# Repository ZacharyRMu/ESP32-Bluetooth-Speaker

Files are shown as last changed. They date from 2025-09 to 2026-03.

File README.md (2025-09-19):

# ESP32 Bluetooth Speaker with Controls

A DIY Bluetooth speaker project using an ESP32 microcontroller, a MAX98357A I²S DAC amplifier, and control buttons. Stream audio via Bluetooth A2DP, and control playback, track navigation, and volume directly from buttons.

---

## Table of Contents

- [Features](#features)  
- [Hardware Requirements](#hardware-requirements)  
- [Circuit / Wiring](#circuit--wiring)  
- [Software & Libraries](#software--libraries)  
- [Usage](#usage)  
- [Troubleshooting](#troubleshooting)  
- [Optional Enhancements](#optional-enhancements)  
- [Project Structure](#project-structure)  
- [License](#license)

---

## Features

- Bluetooth A2DP audio streaming from any compatible device (phone, computer, etc.)  
- Physical controls: play/pause, next/previous track, volume up/down  
- Uses I²S interface with MAX98357A amplifier for better audio quality  
- Configurable and extensible (add LEDs, battery, enclosures, etc.)

---

## Hardware Requirements

| Component | Description / Notes |
|---|---|
| ESP32 board | Any variant that supports Bluetooth + I²S; power via USB or external supply |
| MAX98357A I²S amplifier module | To convert digital audio to analog and drive the speaker |
| Speaker | 4 Ω or 8 Ω, approx. 3 W recommended |
| Push-buttons (×5) | For Play/Pause, Next Track, Previous Track, Volume Up, Volume Down |
| Jumper wires | For connections between ESP32, amplifier, buttons |
| Capacitor (10 µF, optional) | Between VIN and GND of amplifier to smooth power & reduce noise |
| Micro-USB cable | To program and power the ESP32 |
| Enclosure (optional) | To house the electronics nicely and safely |

---

## Circuit / Wiring

**Connections:**

- **Power**  
  - VIN on ESP32 → VIN on MAX98357A  
  - GND → GND (common ground)

- **I²S Audio Signals**  
  - I²S_BCLK (bit clock) → GPIO 27  
  - I²S_LRC (word select / left-right clock) → GPIO 14  
  - I²S_DIN (audio data) → GPIO 26  

- **Buttons** (one side of each button to GND; the other to the ESP32 GPIO pins)  
  - Play/Pause → GPIO 5  
  - Previous Track → GPIO 18  
  - Next Track → GPIO 19  
  - Volume Up → GPIO 21  
  - Volume Down → GPIO 22  

- **Optional components**  
  - 10 µF capacitor between VIN & GND at the amplifier module (reduces noise)  
  - If using amplifier shutdown / gain pins, connect per the datasheet or leave floating if unused

---

## Software & Libraries

- **Arduino IDE / PlatformIO**  
- Required libraries:  
  - [ESP32-A2DP](https://github.com/pschatzmann/ESP32-A2DP) — for Bluetooth audio sink  
  - [Arduino-Audio-Tools](https://github.com/pschatzmann/arduino-audio-tools) — for I²S & audio stream handling  

**Basic flow:**  
1. Initialize I²S stream with the given pins  
2. Start Bluetooth A2DP sink (set device name, default volume)  
3. In main loop, poll buttons with debounce logic  
4. On button presses, issue commands: play/pause, next, previous, volume up/down  

---

## Usage

1. Clone this repository.  
2. Install required libraries (Arduino IDE library manager / PlatformIO, or clone directly).  
3. Connect hardware per wiring instructions.  
4. Upload the code to the ESP32.  
5. Power it up.  
6. On your phone/computer, pair with Bluetooth device named **“ESPEAKER”** (default).  
7. Play audio and use the buttons to control playback and volume.  

---

## Troubleshooting

| Issue | Possible Cause | Solution |
|---|---|---|
| No audio / speaker silent | Wiring error; amplifier VIN not powered; ground not common | Double-check wiring; ensure amplifier module is powered; verify I²S pins match code |
| Distorted or noisy audio | Voltage supply noisy; missing capacitor; gain too high | Add the 10 µF capacitor; check amplifier gain settings; use a clean power supply |
| Buttons not responding | Wrong pins; no pull-ups; bouncing | Make sure button pins match code; use `INPUT_PULLUP` mode; implement debounce |
| BLE not pairing / not visible | Device name wrong; Bluetooth not started; power issues | Confirm `a2dp_sink.start("ESPEAKER")` runs; check ESP32’s Bluetooth functionality |

---

## Optional Enhancements

- Add battery power (for portability), e.g. LiPo + charging circuit (e.g., TP4056)  
- Enclosure: 3D-printed, wooden box, repurposed case  
- Status LEDs: indicate pairing, connected, playing state  
- RGB LEDs synced to music for visual effects  
---

## License

Specify your license here. For example: MIT License — see [LICENSE](LICENSE) file.

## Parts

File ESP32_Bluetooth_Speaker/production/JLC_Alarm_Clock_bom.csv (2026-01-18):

Designator | Footprint | Quantity | Value | LCSC Part #
C1, C2 | 0805 | 2 | 47pF
C10_2 | 0805 | 1 | 10uF
C10, C6, C7 | CP_Elec_6.3x5.4 | 3 | 47uF
C11_2, C11, C12, C16, C3, C4, C5, C8, C9 | 0805 | 9 | 0.1uF
C13, C14 | 0805 | 2 | 220pF
D1 | 0805 | 1 | POWER (RED)
J2 | BarrelJack_CUI_PJ-102AH_Horizontal | 1 | POWER INPUT
Q1, Q2 | SOT-23 | 2 | MMBT3904
R1, R12, R2, R3, R4, R7, R8, R9 | 0805 | 8 | 10k
R10, R11, R13, R14 | 0805 | 4 | 330
R15 | 0805 | 1 | 1M
R5, R6 | 0805 | 2 | 27
RX1 | 0805 | 1 | (GREEN)
SPEAKER | TerminalBlock_RND_205-00232_1x02_P5.08mm_Horizontal | 1 | SPEAKER
SW1 | SW_Tactile_SPST_Angled_PTS645Vx58-2LFS | 1 | PAUSE
SW2 | SW_Tactile_SPST_Angled_PTS645Vx58-2LFS | 1 | PREV
SW3 | SW_Tactile_SPST_Angled_PTS645Vx58-2LFS | 1 | NEXT
SW4 | SW_Tactile_SPST_Angled_PTS645Vx58-2LFS | 1 | V+
SW5 | SW_Tactile_SPST_Angled_PTS645Vx58-2LFS | 1 | V-
SW6 | SKQYAAE010 | 1 | RESET
TX1 | 0805 | 1 | (AMBER)
U1 | SSOP-20_3.9x8.7mm_P0.635mm | 1 | FT231XS
U2 | ESP32-WROOM-32D | 1 | ESP32-WROOM-32E
U3 | TO-252-2 | 1 | NCP1117
U4 | TQFN-16-1EP_3x3mm_P0.5mm_EP1.23x1.23mm | 1 | MAX98357A
USB | USB_Mini-B_Wuerth_65100516121_Horizontal | 1 | USB_B_Mini
USER1 | 0805 | 1 | (RED)

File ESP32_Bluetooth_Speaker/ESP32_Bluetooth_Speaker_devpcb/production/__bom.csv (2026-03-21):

Designator | Footprint | Quantity | Value | LCSC Part #
C1 | CP_Radial_D6.3mm_P2.50mm | 1 | 47uF
C2 | CP_Radial_D6.3mm_P2.50mm | 1 | 10uF
D1 | LED_D5.0mm | 1 | LED
J1 | BarrelJack_CUI_PJ-102AH_Horizontal | 1 | POWER INPUT
R1, R2, R3, R4, R5 | R_Axial_DIN0207_L6.3mm_D2.5mm_P7.62mm_Horizontal | 5 | 10k
R6 | R_Axial_DIN0207_L6.3mm_D2.5mm_P7.62mm_Horizontal | 1 | 330
SW1 | SW_Tactile_SPST_Angled_PTS645Vx58-2LFS | 1 | PAUSE
SW2 | SW_Tactile_SPST_Angled_PTS645Vx58-2LFS | 1 | PREV
SW3 | SW_Tactile_SPST_Angled_PTS645Vx58-2LFS | 1 | NEXT
SW4 | SW_Tactile_SPST_Angled_PTS645Vx58-2LFS | 1 | V+
SW5 | SW_Tactile_SPST_Angled_PTS645Vx58-2LFS | 1 | V-
U1 | esp32_devkit_v1_doit | 1 | ESP32_DevKit_V1_DOIT
U2 | PinSocket_1x07_P2.54mm_Vertical | 1 | ~

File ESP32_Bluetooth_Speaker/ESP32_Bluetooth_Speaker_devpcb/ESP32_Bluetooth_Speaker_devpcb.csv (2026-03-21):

Reference | Qty | Value | DNP | Exclude from BOM | Exclude from Board | Footprint | Datasheet
C1 | 1 | 47uF |  |  |  | Capacitor_THT:CP_Radial_D6.3mm_P2.50mm
C2 | 1 | 10uF |  |  |  | Capacitor_THT:CP_Radial_D6.3mm_P2.50mm | ~
D1 | 1 | LED |  |  |  | LED_THT:LED_D5.0mm | ~
J1 | 1 | POWER INPUT |  |  |  | Connector_BarrelJack:BarrelJack_CUI_PJ-102AH_Horizontal | ~
R1,R2,R3,R4,R5 | 5 | 10k |  |  |  | Resistor_THT:R_Axial_DIN0207_L6.3mm_D2.5mm_P7.62mm_Horizontal | ~
R6 | 1 | 330 |  |  |  | Resistor_THT:R_Axial_DIN0207_L6.3mm_D2.5mm_P7.62mm_Horizontal | ~
SW1 | 1 | PAUSE |  |  |  | Button_Switch_THT:SW_Tactile_SPST_Angled_PTS645Vx58-2LFS | ~
SW2 | 1 | PREV |  |  |  | Button_Switch_THT:SW_Tactile_SPST_Angled_PTS645Vx58-2LFS | ~
SW3 | 1 | NEXT |  |  |  | Button_Switch_THT:SW_Tactile_SPST_Angled_PTS645Vx58-2LFS | ~
SW4 | 1 | V+ |  |  |  | Button_Switch_THT:SW_Tactile_SPST_Angled_PTS645Vx58-2LFS | ~
SW5 | 1 | V- |  |  |  | Button_Switch_THT:SW_Tactile_SPST_Angled_PTS645Vx58-2LFS | ~
U1 | 1 | ESP32_DevKit_V1_DOIT |  |  |  | esp32_devkit_v1_doit:esp32_devkit_v1_doit
U2 | 1 | ~ |  |  |  | Connector_PinSocket_2.54mm:PinSocket_1x07_P2.54mm_Vertical

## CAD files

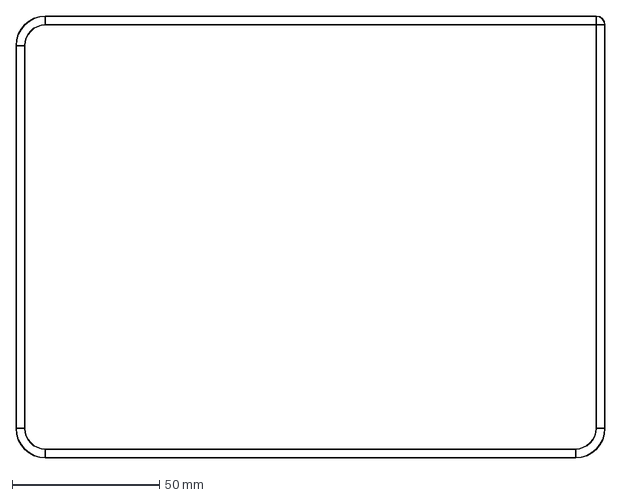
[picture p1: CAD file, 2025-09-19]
Back Horn Speaker Enclosure/Speaker_Side_Bottom_Wood.dxf
200.0 x 150.0 mm

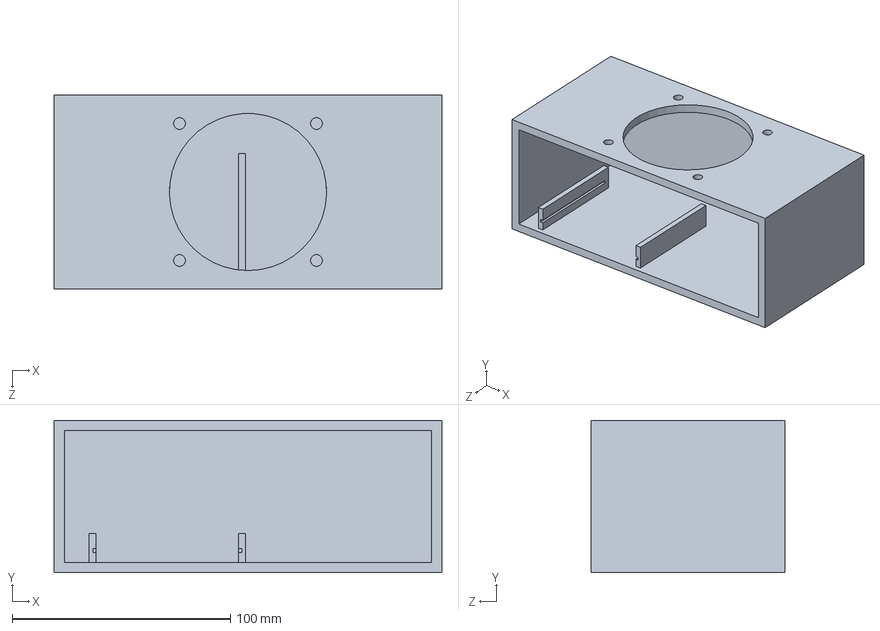
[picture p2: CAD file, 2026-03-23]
compact_enclosure/compact_enclosure_case.SLDPRT
177.8 x 69.8 x 88.9 mm

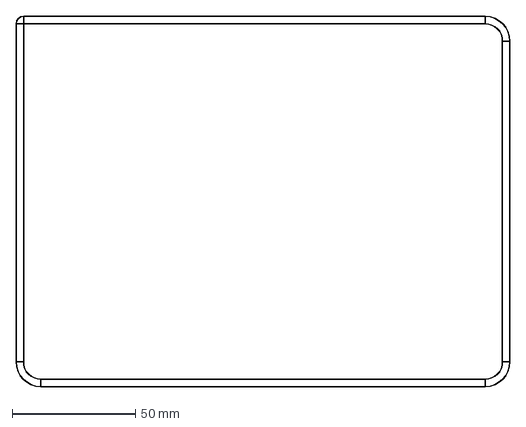
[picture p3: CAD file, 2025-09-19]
Back Horn Speaker Enclosure/Speaker_Side_Top_Wood.dxf
200.0 x 150.0 mm

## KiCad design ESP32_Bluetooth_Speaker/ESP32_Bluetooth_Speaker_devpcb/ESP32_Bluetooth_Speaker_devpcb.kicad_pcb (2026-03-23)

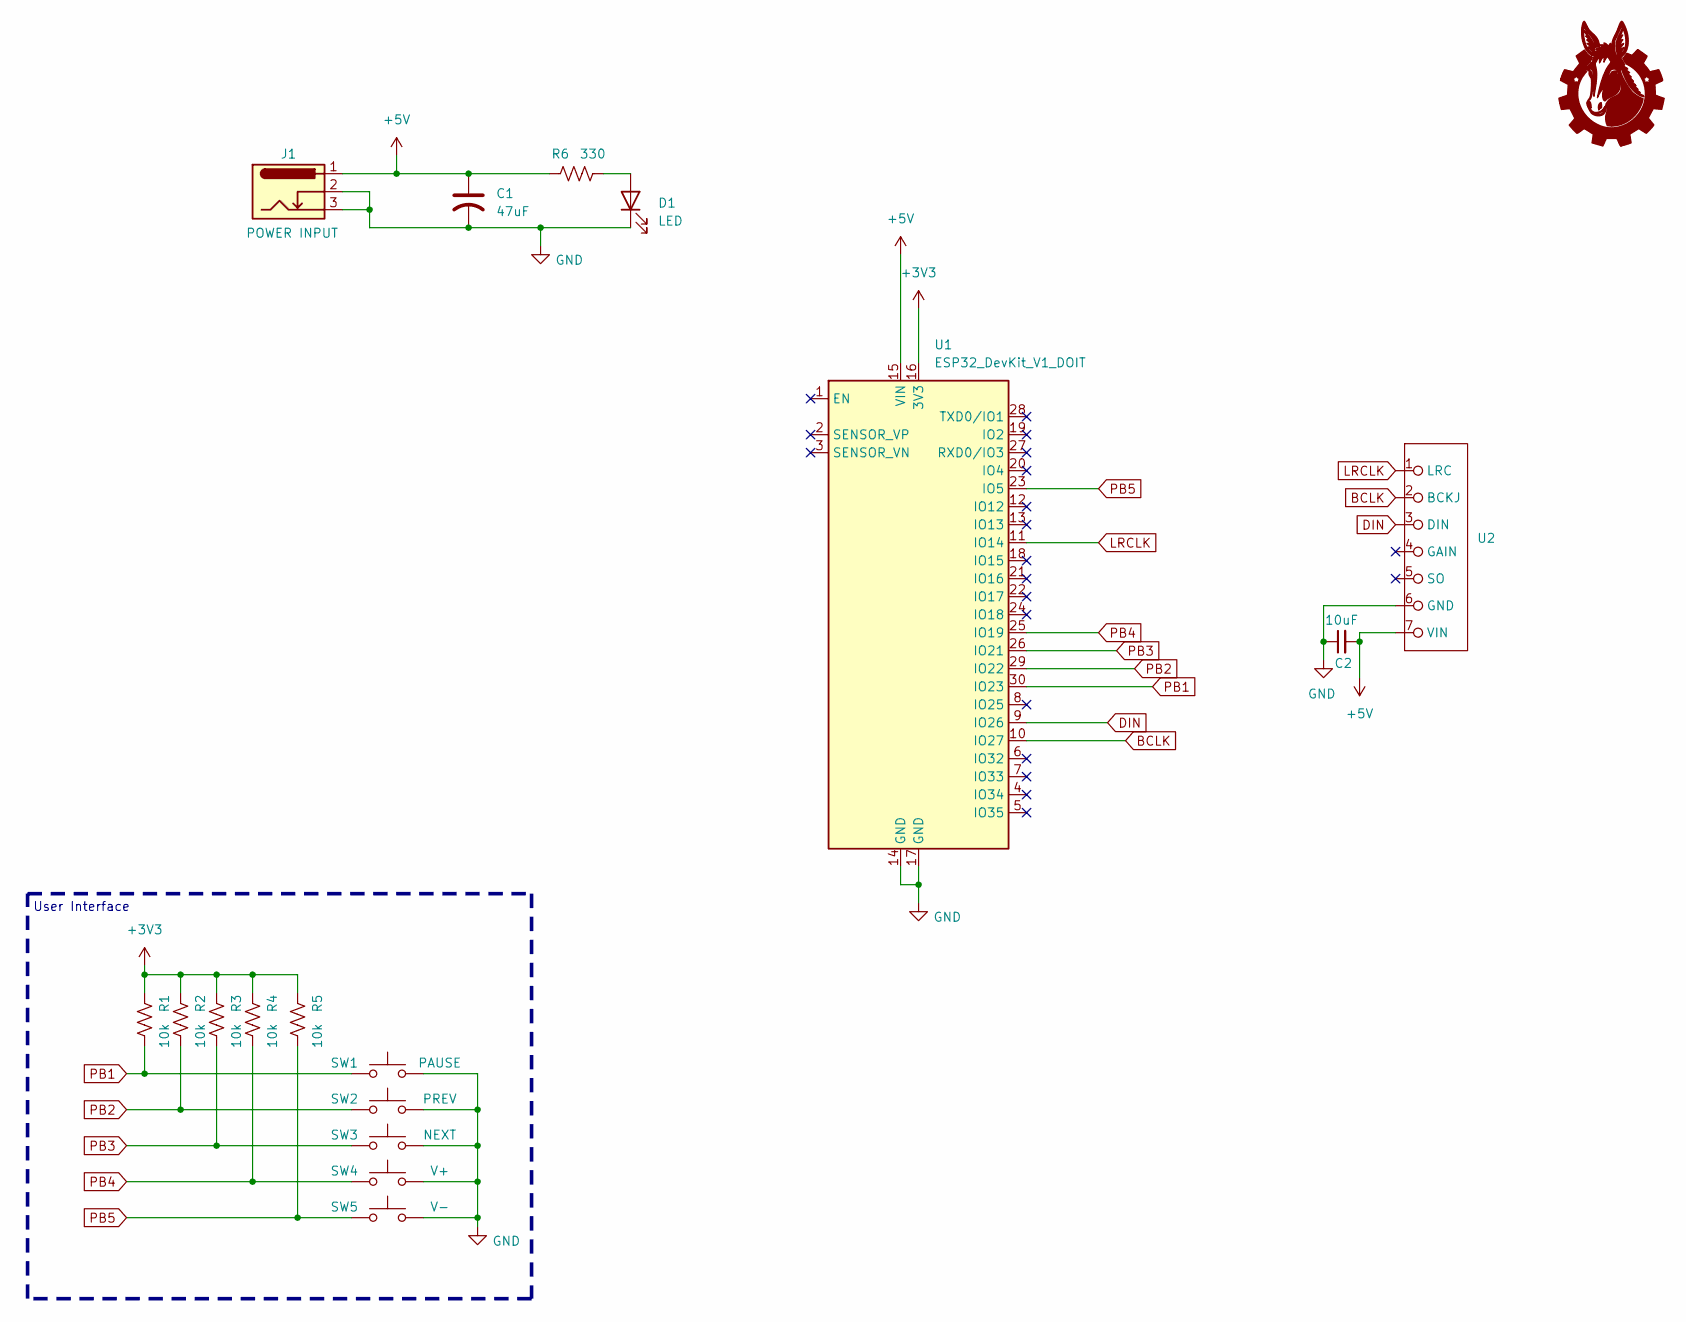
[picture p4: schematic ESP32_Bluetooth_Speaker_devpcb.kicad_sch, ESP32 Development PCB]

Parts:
C1: 47uF; CP_Radial_D6.3mm_P2.50mm
C2: 10uF; CP_Radial_D6.3mm_P2.50mm
D1: LED; LED_D5.0mm
J1: POWER INPUT; BarrelJack_CUI_PJ-102AH_Horizontal
R1, R2, R3, R4, R5: 10k; R_Axial_DIN0207_L6.3mm_D2.5mm_P7.62mm_Horizontal
R6: 330; R_Axial_DIN0207_L6.3mm_D2.5mm_P7.62mm_Horizontal
SW1: PAUSE; SW_Tactile_SPST_Angled_PTS645Vx58-2LFS
SW2: PREV; SW_Tactile_SPST_Angled_PTS645Vx58-2LFS
SW3: NEXT; SW_Tactile_SPST_Angled_PTS645Vx58-2LFS
SW4: V+; SW_Tactile_SPST_Angled_PTS645Vx58-2LFS
SW5: V-; SW_Tactile_SPST_Angled_PTS645Vx58-2LFS
U1: ESP32_DevKit_V1_DOIT; esp32_devkit_v1_doit
U2: PinSocket_1x07_P2.54mm_Vertical

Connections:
+3V3: R1.2, R2.2, R3.2, R4.2, R5.2, U1.16 (3V3)
+5V: C1.1, C2.2, J1.1, R6.2, U1.15 (VIN), U2.7 (VIN)
BCLK: U1.10 (IO27), U2.2 (BCKJ)
DIN: U1.9 (IO26), U2.3 (DIN)
GND: C1.2, C2.1, D1.1 (K), J1.2, J1.3, SW1.2, SW2.2, SW3.2, SW4.2, SW5.2, U1.14 (GND), U1.17 (GND), U2.6 (GND)
LRCLK: U1.11 (IO14), U2.1 (LRC)
unnamed: D1.2 (A), R6.1
PB1: R1.1, SW1.1, U1.30 (IO23)
PB2: R2.1, SW2.1, U1.29 (IO22)
PB3: R3.1, SW3.1, U1.26 (IO21)
PB4: R4.1, SW4.1, U1.25 (IO19)
PB5: R5.1, SW5.1, U1.23 (IO5)

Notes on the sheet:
User Interface

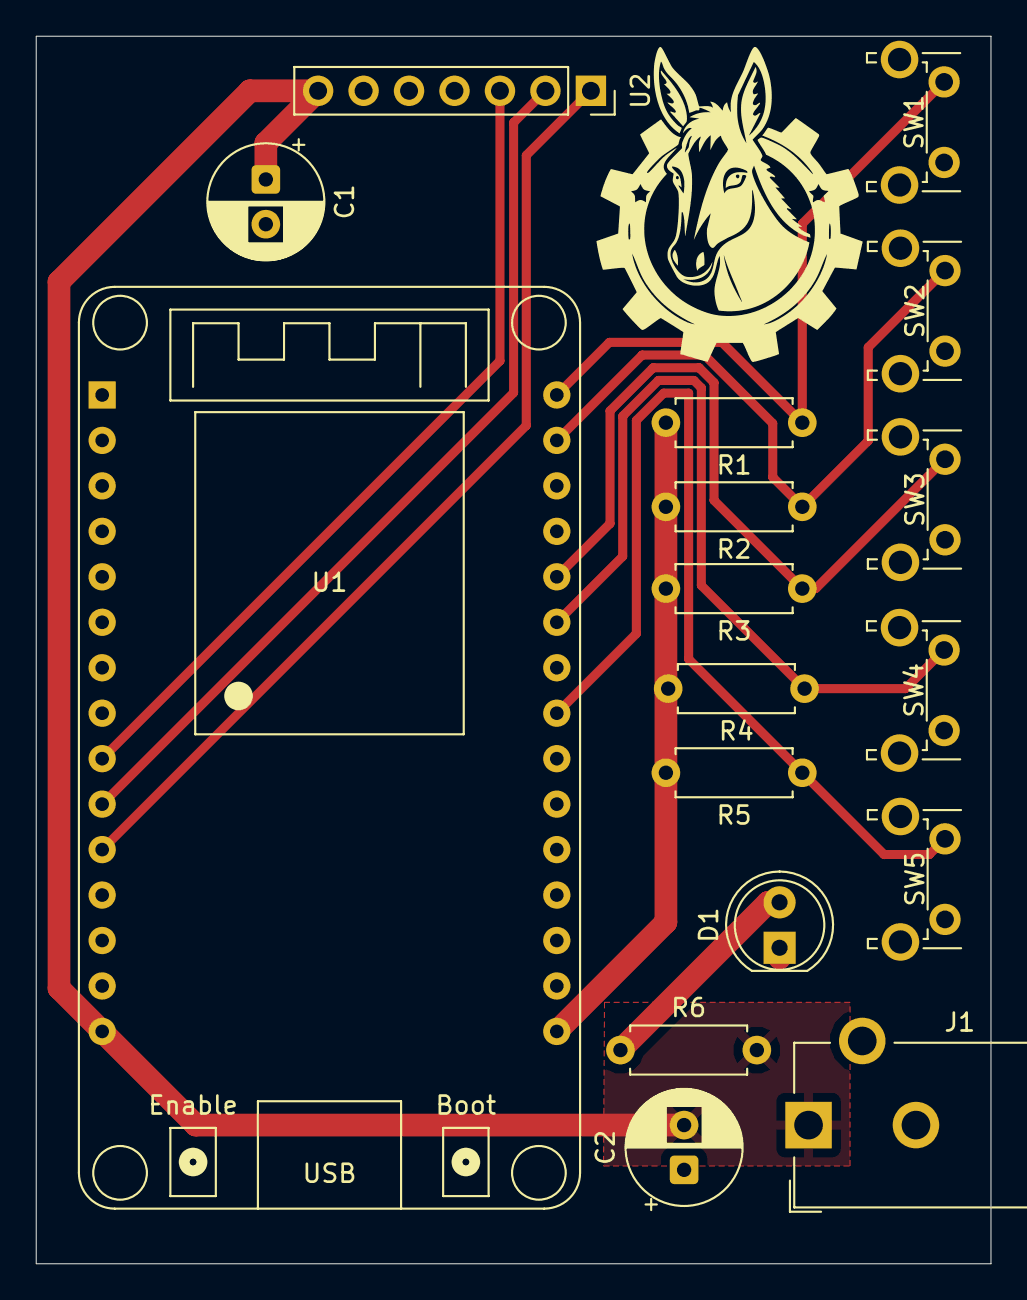
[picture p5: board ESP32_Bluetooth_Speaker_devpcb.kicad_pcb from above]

Board: 2 copper layers, 53.3 x 68.6 mm, 17 parts (0 on the bottom side), 12 nets.

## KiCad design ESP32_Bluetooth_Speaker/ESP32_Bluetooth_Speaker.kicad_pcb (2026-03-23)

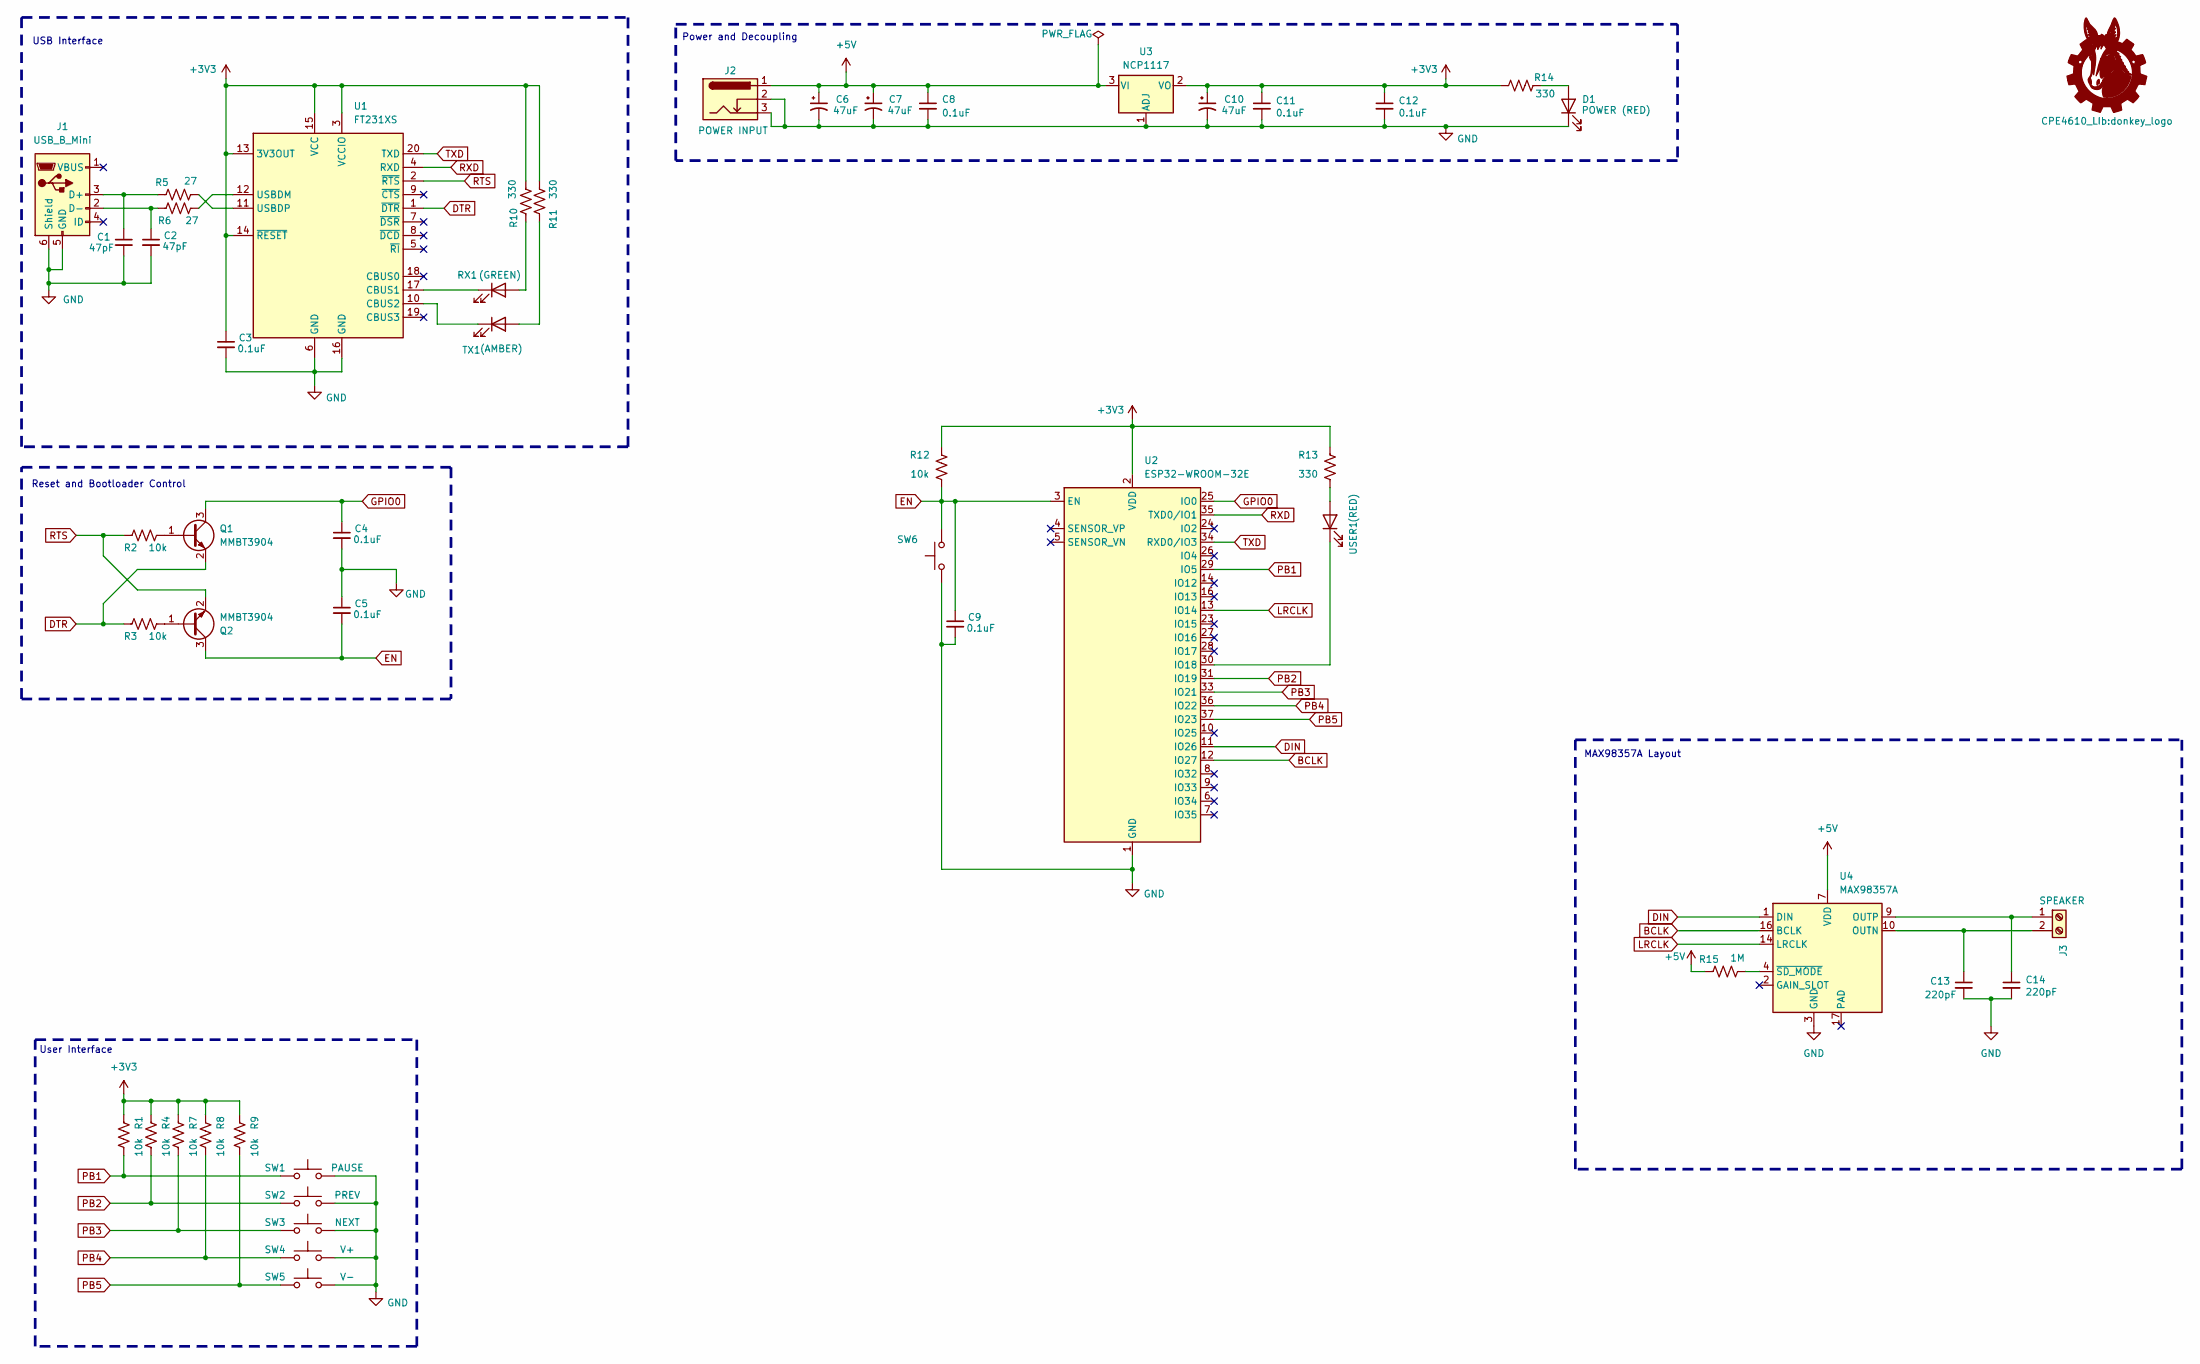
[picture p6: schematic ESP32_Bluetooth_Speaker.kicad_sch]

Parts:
C1, C2: 47pF; C_0805_2012Metric
C3, C4, C5, C8, C9, C11, C12: 0.1uF; C_0805_2012Metric
C6, C7, C10: 47uF; CP_Elec_6.3x5.4
C13, C14: 220pF; C_0805_2012Metric
D1: POWER (RED); LED_0805_2012Metric
J1: USB_B_Mini; USB_Mini-B_Wuerth_65100516121_Horizontal
J2: POWER INPUT; BarrelJack_CUI_PJ-102AH_Horizontal
J3: SPEAKER; TerminalBlock_RND_205-00232_1x02_P5.08mm_Horizontal
Q1, Q2: MMBT3904; SOT-23
R1, R2, R3, R4, R7, R8, R9, R12: 10k; R_0805_2012Metric
R5, R6: 27; R_0805_2012Metric
R10, R11, R13, R14: 330; R_0805_2012Metric
R15: 1M; R_0805_2012Metric
RX1: (GREEN); LED_0805_2012Metric
SW1: PAUSE; SW_Tactile_SPST_Angled_PTS645Vx58-2LFS
SW2: PREV; SW_Tactile_SPST_Angled_PTS645Vx58-2LFS
SW3: NEXT; SW_Tactile_SPST_Angled_PTS645Vx58-2LFS
SW4: V+; SW_Tactile_SPST_Angled_PTS645Vx58-2LFS
SW5: V-; SW_Tactile_SPST_Angled_PTS645Vx58-2LFS
SW6: RESET; SKQYAAE010
TX1: (AMBER); LED_0805_2012Metric
U1: FT231XS; SSOP-20_3.9x8.7mm_P0.635mm
U2: ESP32-WROOM-32E; ESP32-WROOM-32D
U3: NCP1117; TO-252-2
U4: MAX98357A; TQFN-16-1EP_3x3mm_P0.5mm_EP1.23x1.23mm
USER1: (RED); LED_0805_2012Metric

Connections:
+3V3: C3.1, C10.1, C11.1, C12.1, R1.2, R4.2, R7.2, R8.2, R9.2, R10.2, R11.2, R12.2, R13.2, R14.2, U1.3 (VCCIO), U1.13 (3V3OUT), U1.14 (~RESET), U1.15 (VCC), U2.2 (VDD), U3.2 (VO)
+5V: C6.1, C7.1, C8.1, J2.1, R15.1, U3.3 (VI), U4.7 (VDD), U4.8 (VDD)
BCLK: U2.12 (IO27), U4.16 (BCLK)
DIN: U2.11 (IO26), U4.1 (DIN)
DTR: Q1.2 (E), R3.1, U1.1 (~DTR)
EN: C5.2, C9.1, Q2.3 (C), R12.1, SW6.2, U2.3 (EN)
GND: C1.2, C2.2, C3.2, C4.2, C5.1, C6.2, C7.2, C8.2, C9.2, C10.2, C11.2, C12.2, C13.2, C14.2, D1.1 (K), J1.5 (GND), J1.6 (Shield), J2.2, J2.3, SW1.2, SW2.2, SW3.2, SW4.2, SW5.2, SW6.1, U1.6 (GND), U1.16 (GND), U2.1 (GND), U2.15 (GND), U2.38 (GND), U2.39 (GND), U3.1 (ADJ), U4.3 (GND), U4.11 (GND), U4.15 (GND)
GPIO0: C4.1, Q1.3 (C), U2.25 (IO0)
LRCLK: U2.13 (IO14), U4.14 (LRCLK)
unnamed: D1.2 (A), R14.1
unnamed: C1.1, J1.3 (D+), R5.1
unnamed: C2.1, J1.2 (D-), R6.1
unnamed: C14.1, J3.1, U4.9 (OUTP)
unnamed: C13.1, J3.2, U4.10 (OUTN)
unnamed: Q1.1 (B), R2.2
unnamed: Q2.1 (B), R3.2
unnamed: R10.1, RX1.2 (A)
unnamed: RX1.1 (K), U1.17 (CBUS1)
unnamed: R11.1, TX1.2 (A)
unnamed: TX1.1 (K), U1.10 (CBUS2)
unnamed: R6.2, U1.12 (USBDM)
unnamed: R5.2, U1.11 (USBDP)
unnamed: U2.30 (IO18), USER1.1 (K)
unnamed: R15.2, U4.4 (~SD_MODE)
unnamed: R13.1, USER1.2 (A)
PB1: R1.1, SW1.1, U2.29 (IO5)
PB2: R4.1, SW2.1, U2.31 (IO19)
PB3: R7.1, SW3.1, U2.33 (IO21)
PB4: R8.1, SW4.1, U2.36 (IO22)
PB5: R9.1, SW5.1, U2.37 (IO23)
RTS: Q2.2 (E), R2.1, U1.2 (~RTS)
RXD: U1.4 (RXD), U2.35 (TXD0/IO1)
TXD: U1.20 (TXD), U2.34 (RXD0/IO3)

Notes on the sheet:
USB Interface
Power and Decoupling
User Interface
MAX98357A Layout
Reset and Bootloader Control

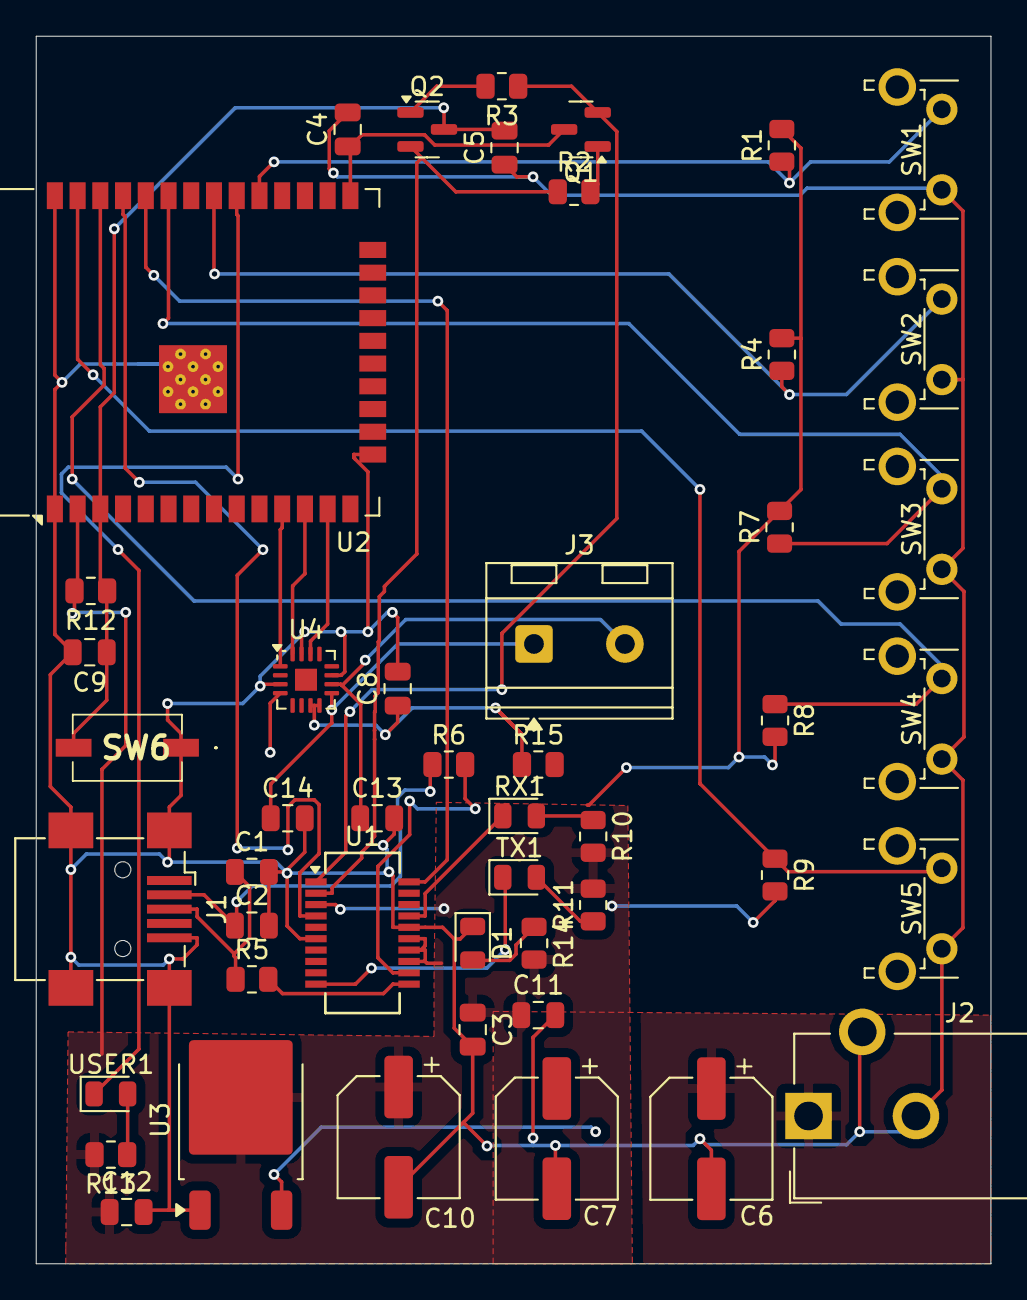
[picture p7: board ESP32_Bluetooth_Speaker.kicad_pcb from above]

Board: 2 copper layers, 53.3 x 68.6 mm, 48 parts (0 on the bottom side), 33 nets.

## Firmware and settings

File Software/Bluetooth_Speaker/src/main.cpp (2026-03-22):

#include <Arduino.h>
#include <Audiotools.h>
#include <BluetoothA2DPSink.h>

// Button GPIO pins 
#define BUTTON_PLAY_PAUSE 5
#define BUTTON_PREVIOUS 18
#define BUTTON_NEXT 19
#define BUTTON_VOLUME_UP 21
#define BUTTON_VOLUME_DOWN 22

#define I2S_LRC 14
#define I2S_BCLK 27
#define I2S_DIN 26

// I2S and Bluetooth Link 
I2SStream i2s; 
BluetoothA2DPSink a2dp_sink(i2s);

// buttons states
bool lastPlayPauseState = HIGH;
bool lastPreviousState = HIGH;
bool lastNextState = HIGH;
bool lastVolumeUpState = HIGH;
bool lastVolumeDownState = HIGH;

// playback state 
bool isPlaying = false;



void setup() {
Serial.begin(115200);

// configure buttons 
pinMode(BUTTON_PLAY_PAUSE, INPUT);
pinMode(BUTTON_PREVIOUS, INPUT);
pinMode(BUTTON_NEXT, INPUT);
pinMode(BUTTON_VOLUME_UP, INPUT);
pinMode(BUTTON_VOLUME_DOWN, INPUT);

// configure i2s
auto cfg = i2s.defaultConfig();
cfg.pin_bck = I2S_BCLK; // BCLK pin
cfg.pin_ws = I2S_LRC; // LRC pin
cfg.pin_data = I2S_DIN; // din pin
i2s.begin(cfg);

// start bluteooth link
a2dp_sink.start("ESPEAKER");
a2dp_sink.set_volume(64);
}

void loop() {
  // read button states
  bool currentPlayPauseState = digitalRead(BUTTON_PLAY_PAUSE);
  bool currentPreviousState = digitalRead(BUTTON_PREVIOUS);
  bool currentNextState = digitalRead(BUTTON_NEXT);
  bool currentVolumeUpState = digitalRead(BUTTON_VOLUME_UP);
  bool currentVolumeDownState = digitalRead(BUTTON_VOLUME_DOWN);
  Serial.println(a2dp_sink.get_volume());

  // Handle Play-pause
  if (currentPlayPauseState == LOW && lastPlayPauseState == HIGH) {
    Serial.println("Play/Pause Button Pressed");
    if(isPlaying) {
      a2dp_sink.pause(); // call pause 
      isPlaying = false;
      Serial.println(" Paused");
    } else {
      a2dp_sink.play(); // call play
      isPlaying =  true;
      Serial.println(" Playing");
    }
  }

  lastPlayPauseState = currentPlayPauseState;

  // Handle previous track button
  if(currentPreviousState == LOW && lastPreviousState == HIGH) {
    Serial.println("Previous Track Button Pressed");
    a2dp_sink.previous(); // go to prior track 
  }
  lastPreviousState = currentPreviousState;
  
  // handle next track button 
  if(currentNextState == LOW && lastNextState == HIGH) {
    Serial.println("Next Track Button Pressed");
    a2dp_sink.next(); // go to next track 
  }
  lastNextState = currentNextState;

  // handle volume up button 
  if(currentVolumeUpState == LOW && lastVolumeUpState == HIGH) {
    Serial.println("Volume up button pressed");
    a2dp_sink.volume_up(); // increment volume by one 
  }
  lastVolumeUpState = currentVolumeUpState;

  // handle volume down button 
  if(currentVolumeDownState == LOW && lastVolumeDownState == HIGH){
    Serial.println("Volume down button pressed");
    a2dp_sink.volume_down(); // decrement volume by one 
  }
  lastVolumeDownState = currentVolumeDownState;

  // short delay to debounce buttonz
  delay(50);
}

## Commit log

2025-09-19 Created Software outline + code from development process. Added 3D CAD speaker enclosure.
    [ESP32_Bluetooth_Speaker.kicad_pcb, ESP32_Bluetooth_Speaker.kicad_sch]
2025-09-19 Added 3D enclosure.
    [Speaker_Side_Bottom_Wood.dxf, Speaker_Side_Top_Wood.dxf]
2025-09-19 Started Schematic capture for PCB.
    [ESP32_Bluetooth_Speaker.kicad_sch]
2026-01-18 Initial Commit for Project
    [ESP32_Bluetooth_Speaker.kicad_pcb, ESP32_Bluetooth_Speaker.kicad_sch]
2026-01-18 Created schematic and PCB.
2026-03-21 Created dev PCB + model
    [ESP32_Bluetooth_Speaker_Dev_PCB_A_bom.csv, ESP32_Bluetooth_Speaker_Dev_PCB_A_designators.csv, ESP32_Bluetooth_Speaker_Dev_PCB_A_positions.csv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]
2026-03-22 ESP32 Code + initial code rev
2026-03-23 Added CAD assembly and surface mount PCB initial rev
    [ESP32_Bluetooth_Speaker.kicad_pcb, ESP32_Bluetooth_Speaker_devpcb.kicad_pcb, compact_enclosure_case.SLDPRT]
